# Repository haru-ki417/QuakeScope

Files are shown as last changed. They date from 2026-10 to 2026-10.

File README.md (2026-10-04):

# QuakeScope



**置いた場所の揺れを測り、気象庁の「計測震度」と同じ考え方で震度相当を出す、ESP32 の揺れ検知アラーム。**
強い揺れでは警報音を鳴らし、LINE・Telegram・Discord・メールに知らせます。判定エンジンは C++ で書き、本体とブラウザー（WebAssembly）で同じものを動かしています。

[**ブラウザーで試す**](https://haru-ki417.github.io/QuakeScope/) — 見本の地震や、スマホのセンサーで、本体と同じ判定を確かめられます。

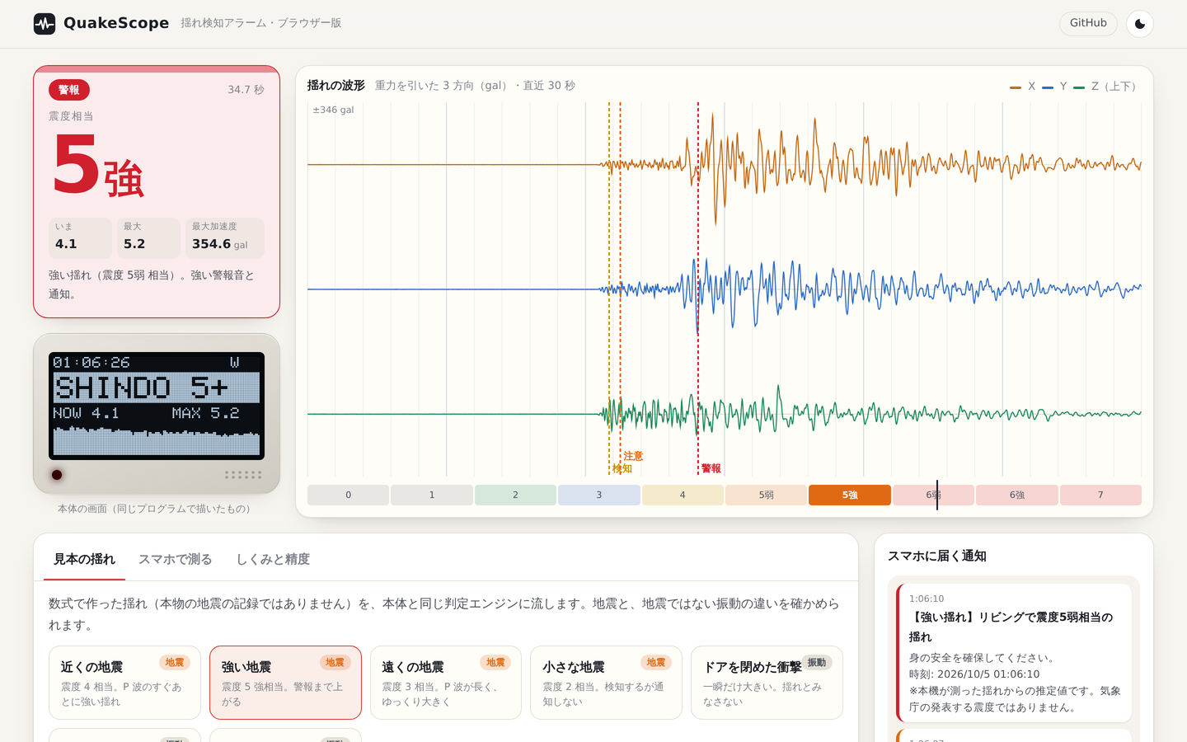
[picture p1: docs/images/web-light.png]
ブラウザー版: 震度 5 強相当の見本の地震を流したところ


> 本機の値は、置いた場所で測った揺れからの**推定（参考値）**です。気象庁の発表する震度・緊急地震速報ではありません。

## できること

| | |
|---|---|
| **震度相当** | 3 方向の加速度に、気象庁の計測震度と同じ周波数特性のフィルターをかけて計算（100 Hz・0.1 秒ごと）。揺れの最中から表示し、終わったら「この揺れの最大」を残す |
| **揺れ始め** | ふだんとの比（STA/LTA）で P 波をとらえ、短い音で知らせる。ドアや足音のような一瞬の衝撃は揺れとみなさない |
| **3 段階の警報** | 揺れ検知（震度 1 相当〜）・注意（震度 3 相当〜）・警報（震度 5 弱相当〜）。目安は変えられる |
| **通知** | LINE（Messaging API）・Telegram・Discord・メール（SMTP）。1 回の揺れで同じレベルは 1 度だけ、収まったらまとめ |
| **記録** | 揺れの要約 50 件と、揺れ始めの 5 秒前からの波形 8 件を本体に保存。スマホで見られる |
| **初期設定はスマホで** | 本体が自分の Wi-Fi を出し、スマホでつなぐと設定画面が開く。Wi-Fi・通知先・警報の目安を画面で設定 |
| **ケースと基板** | 3D プリントのケース（パラメーターで作り直せる）・回路図・ユニバーサル基板の配置と配線表・部品表 |

<p>
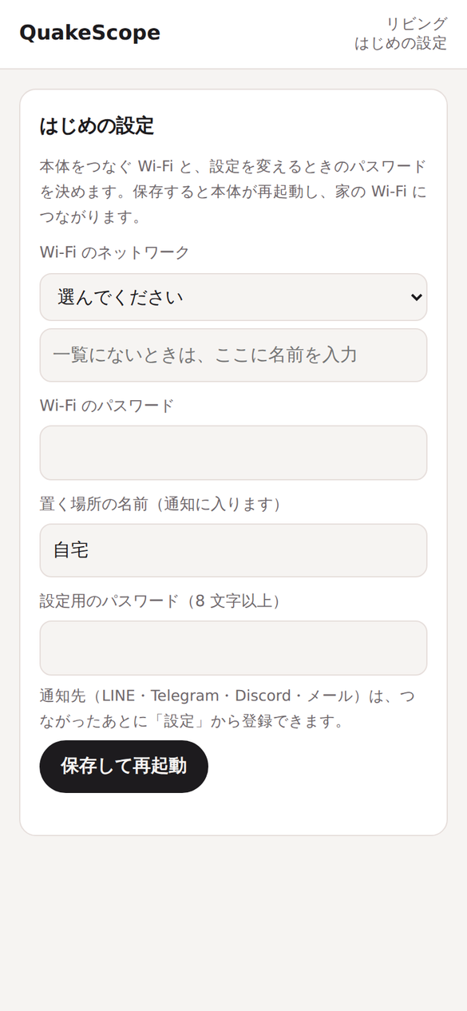
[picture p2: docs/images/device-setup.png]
はじめの設定

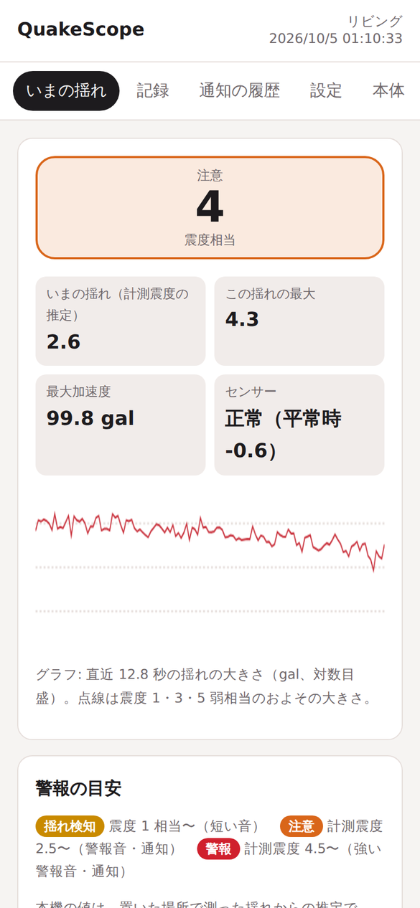
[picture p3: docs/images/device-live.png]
いまの揺れ

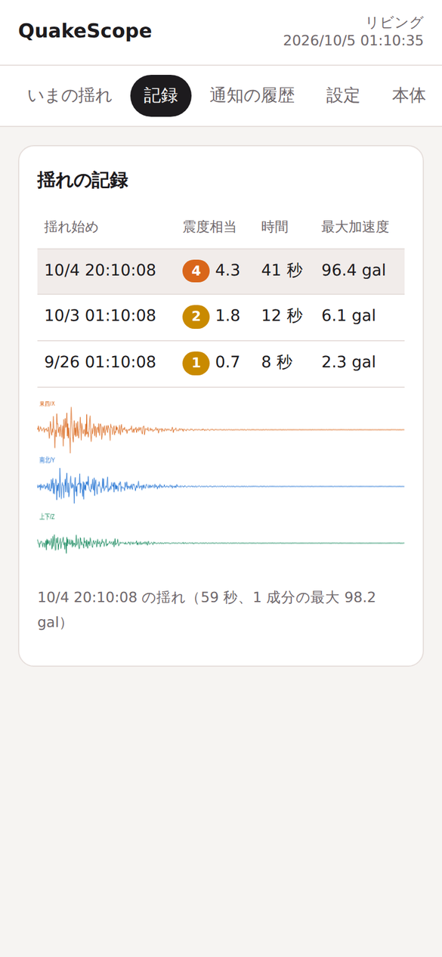
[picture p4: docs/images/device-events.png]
揺れの記録と波形

</p>

本体の設定画面（スマホ）。左から、はじめの設定・いまの揺れ・揺れの記録と波形。

## 精度

| 確かめたこと | 結果 |
|---|---|
| 本体の近似（IIR フィルター）と、気象庁の手順どおりの計算（周波数領域）の差 | 見本の地震 96 本で平均 0.024・最大 0.072 |
| 周波数領域の計算と、numpy で別に書いた計算の差 | 10⁻⁶ 以下 |
| 震度 3 以上の近い地震で、強い揺れ（S 波）の前にとらえるか | 5 通りすべて P 波から 1.5 秒以内 |
| ドア・足音・トラックで注意・警報にならないか | すべてならない |
| MPU6050 の雑音（約 3 gal）を入れた見本 | 雑音だけでは鳴らず、震度 3 以上はとらえる |

**限界**: 本体のセンサー（MPU6050）は雑音が大きいため、**震度 2 相当以下の小さな揺れは見逃すことがあります**。また、高い階やたなの上では、建物の揺れが加わって気象庁の震度より大きく出ることがあります。くわしくは[しくみと精度](docs/how-it-works.md)。

## 作る

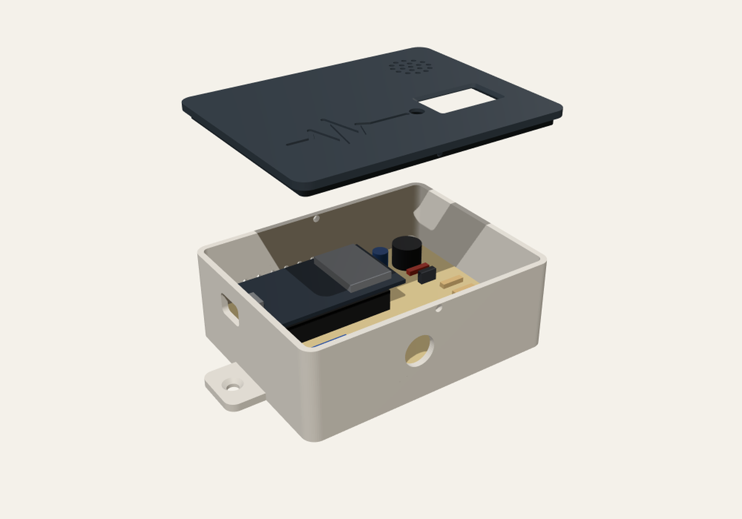
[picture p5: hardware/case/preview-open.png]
ケース


| | |
|---|---|
| [部品表](hardware/BOM.md) | ESP32-DevKitC-32E・GY-521（MPU6050）・0.96″ OLED・電磁ブザー・フルカラー LED・押しボタンなど。電子部品とケースで 4,500〜6,500 円が目安 |
| [回路図](hardware/schematic.svg) | 部品番号つき |
| [基板の配置と配線表](hardware/wiring.md) | 95×72 mm のユニバーサル基板。穴の番号で部品の位置と 29 本の配線を指定 |
| [ケース](hardware/case/) | `case_base.stl`・`case_lid.stl`。寸法は `case.mjs` の `PARAMS` で変えられる |
| [組み立てと書き込み](docs/assembly.md) | はんだ付けの順番・ファームウェアの書き込み・動作の確認・置き方 |

## 使う

- [使い方](docs/manual.md): はじめの設定・画面と LED の見方・ボタン・警報の目安・記録・更新・困ったとき
- [通知の設定](docs/notifications.md): LINE・Telegram・Discord・Gmail の手順

## 中身

```
core/          判定エンジン（C++17・端末に依存しない）とテスト
  src/         震度の計算・揺れの判定・通知の文面・画面の中身・見本の揺れ
  tests/       26 のテスト（275 項目）
  tools/       見本の揺れの CLI・numpy での確認
firmware/
  QuakeScope/  ESP32 のファームウェア（Arduino）。src/qs は core/src の写し
  web/         本体の設定画面（1 枚の HTML。gzip してファームウェアに入れる）
web/           ブラウザー版（WebAssembly・GitHub Pages）
hardware/      回路図・基板の配置・部品表・ケース
tools/         フィルターの係数を求める・core の写し・設定画面の埋め込み・本体のまね（モック）
docs/          使い方・通知・組み立て・しくみ
legacy/        試作 1 号機（Arduino Uno 版）のスケッチ
```

## 開発

```sh
# エンジンのテスト
cd core/tests && c++ -std=c++17 -O2 -Wall -Wextra -Werror -I../src test_core.cpp ../src/*.cpp -o test_core && ./test_core

# core/src を変えたら、ファームウェアに写す（CI は --check で確かめる）
python3 tools/sync_core.py

# 設定画面（firmware/web/index.html）を変えたら、ファームウェアに埋め込む
python3 tools/embed_web.py

# ブラウザー版の WebAssembly（wasi-sdk が要る）
WASI_SDK=/path/to/wasi-sdk web/build_wasm.sh
python3 -m http.server -d web 8000   # http://localhost:8000/

# 本体なしで設定画面を試す（見本の揺れを流す、本体のまね）
c++ -std=c++17 -O2 -Icore/src core/tools/qs_cli.cpp core/src/*.cpp -o qs_cli
python3 tools/mock_device.py ./qs_cli --port 8080          # 設定済みの本体
python3 tools/mock_device.py ./qs_cli --setup --port 8081  # はじめの設定

# ファームウェア
arduino-cli compile --fqbn esp32:esp32:esp32:PartitionScheme=min_spiffs firmware/QuakeScope

# 回路図・基板の配置・ケース
python3 tools/hw/schematic.py && python3 tools/hw/layout.py
cd hardware/case && npm install && node case.mjs
```

## 安全と法令について

- **気象業務法**: 気象庁以外の者が地震動の**予報**（ほかの場所の揺れや、これから来る揺れの予想）を業務として行うには、気象庁長官の許可が要ります。QuakeScope は、置いた場所で**測った揺れをそのまま表示・通知するだけ**で、予想はしません。通知の文にも、気象庁の震度ではないことを必ず入れています。参考: [気象庁「地震動の予報業務許可」](https://www.jma.go.jp/jma/kishou/minkan/minkan_jishin.html)
- **電波法（技適）**: 日本で使うときは、技適マークのある ESP32 モジュール（ESP32-WROOM-32E など）を使ってください。
- **電源**: PSE マークのある USB AC アダプターを使ってください。停電すると本体もルーターも止まります。[停電と通信](docs/manual.md#停電と通信)を見てください。
- **通知だけに頼らない**: 通信の混雑で、通知は遅れたり届かなかったりします。強い揺れを感じたら、まず身の安全を確保してください。

## 試作 1 号機

QuakeScope は、Arduino Uno で作った「地震即時アラートシステム」を作り直したものです。試作のスケッチと、作り直すときに見つけた問題と対処を [legacy/uno-prototype](legacy/uno-prototype/) に残しています。

## ライセンス

[MIT License](LICENSE)。ほかの人が作ったものは [THIRD_PARTY.md](THIRD_PARTY.md)。

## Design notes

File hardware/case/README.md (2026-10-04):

# ケース

| ファイル | 中身 |
|---|---|
| `case_base.stl` | 底（基板を留める柱 4 本・USB の口・前の壁にボタンの穴・後ろの壁に空気の通り道・左右に床へ留める耳） |
| `case_lid.stl` | ふた（OLED の窓・LED の穴・ブザーの音の穴・地震計の波形の模様）。印刷する向き（表を下）で入っている |
| `case.mjs` | 上の 2 つを作るプログラム。寸法は先頭の `PARAMS` で変えられる |

外形は 102.8 × 79.8 × 38.6 mm（耳を除く）。印刷の設定と組み立ては[組み立てと書き込み](../../docs/assembly.md)を見てください。

```sh
npm install     # manifold-3d
node case.mjs   # STL を作り直す（../layout.json の部品の位置に合わせて穴を開ける）
```

| 組み立てた姿 | 中 | ふたの裏 |
|---|---|---|
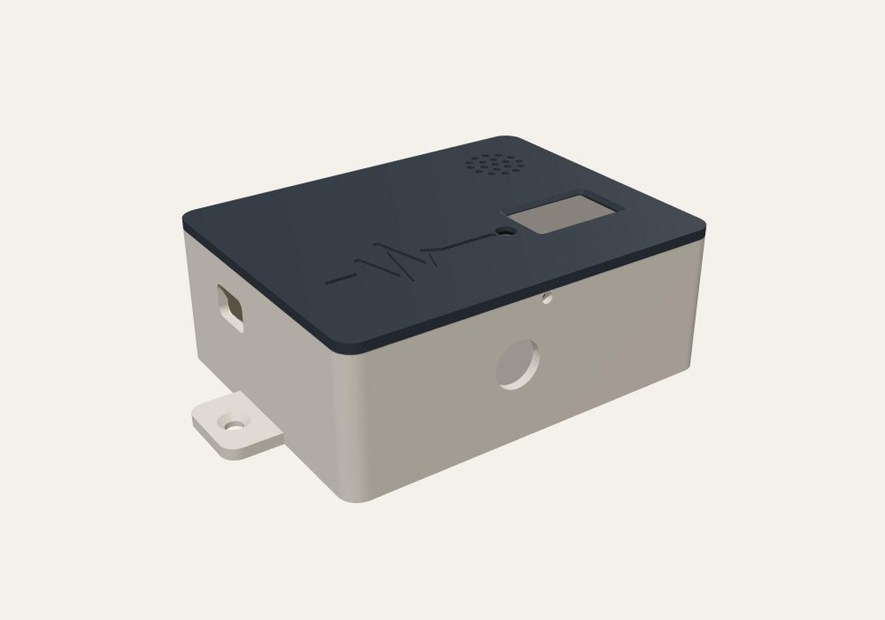
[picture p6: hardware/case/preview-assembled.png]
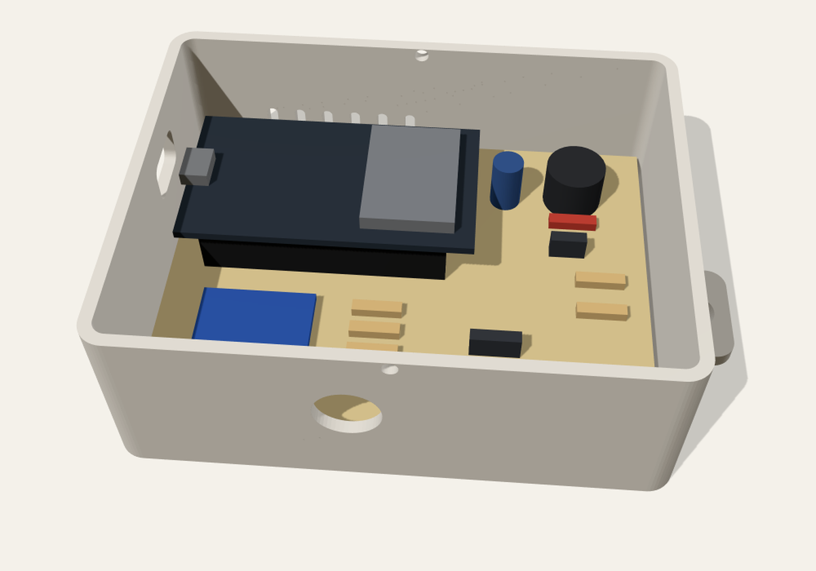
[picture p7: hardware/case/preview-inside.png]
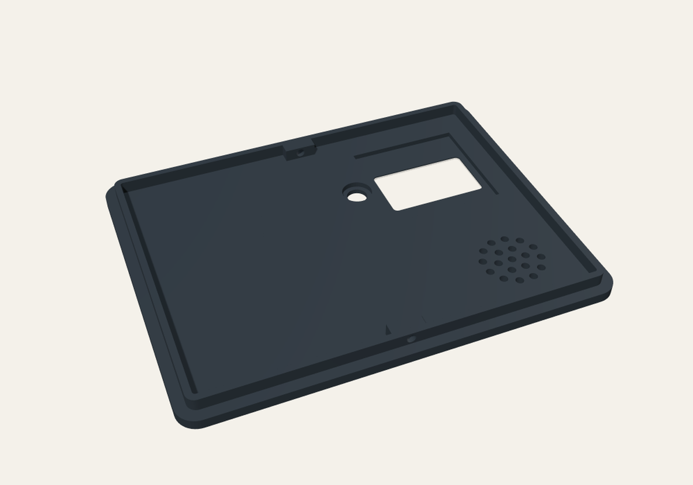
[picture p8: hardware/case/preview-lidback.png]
|  |  |  |

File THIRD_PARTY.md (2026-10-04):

# ほかの人が作ったもの

QuakeScope は、次のソフトウェアを使っています。

| 名前 | 使っている所 | ライセンス | リポジトリに含むか |
|---|---|---|---|
| [Adafruit SSD1306](https://github.com/adafruit/Adafruit_SSD1306) | ファームウェア（OLED） | BSD | 含まない（Arduino のライブラリマネージャーで入れる） |
| [Adafruit GFX Library](https://github.com/adafruit/Adafruit-GFX-Library) | ファームウェア（文字・図形） | BSD | 文字の形（glcdfont.c の ASCII 部分）だけ `web/js/font5x7.js` に含む |
| [Adafruit BusIO](https://github.com/adafruit/Adafruit_BusIO) | ファームウェア | MIT | 含まない |
| [Arduino core for ESP32](https://github.com/espressif/arduino-esp32) | ファームウェア | LGPL-2.1 | 含まない |
| [manifold-3d](https://github.com/elalish/manifold) | ケースの STL を作る道具 | Apache-2.0 | 含まない（`npm install` で入れる） |
| [wasi-sdk](https://github.com/WebAssembly/wasi-sdk) | ブラウザー版の WebAssembly を作る道具 | Apache-2.0 WITH LLVM-exception | 道具は含まない。`web/qs.wasm` には、その C/C++ ランタイム（wasi-libc・libc++）の一部が入る |

## Adafruit GFX Library（glcdfont.c）

```
Software License Agreement (BSD License)

Copyright (c) 2012 Adafruit Industries.  All rights reserved.

Redistribution and use in source and binary forms, with or without
modification, are permitted provided that the following conditions are met:

- Redistributions of source code must retain the above copyright notice,
  this list of conditions and the following disclaimer.
- Redistributions in binary form must reproduce the above copyright notice,
  this list of conditions and the following disclaimer in the documentation
  and/or other materials provided with the distribution.

THIS SOFTWARE IS PROVIDED BY THE COPYRIGHT HOLDERS AND CONTRIBUTORS "AS IS"
AND ANY EXPRESS OR IMPLIED WARRANTIES, INCLUDING, BUT NOT LIMITED TO, THE
IMPLIED WARRANTIES OF MERCHANTABILITY AND FITNESS FOR A PARTICULAR PURPOSE
ARE DISCLAIMED. IN NO EVENT SHALL THE COPYRIGHT HOLDER OR CONTRIBUTORS BE
LIABLE FOR ANY DIRECT, INDIRECT, INCIDENTAL, SPECIAL, EXEMPLARY, OR
CONSEQUENTIAL DAMAGES (INCLUDING, BUT NOT LIMITED TO, PROCUREMENT OF
SUBSTITUTE GOODS OR SERVICES; LOSS OF USE, DATA, OR PROFITS; OR BUSINESS
INTERRUPTION) HOWEVER CAUSED AND ON ANY THEORY OF LIABILITY, WHETHER IN
CONTRACT, STRICT LIABILITY, OR TORT (INCLUDING NEGLIGENCE OR OTHERWISE)
ARISING IN ANY WAY OUT OF THE USE OF THIS SOFTWARE, EVEN IF ADVISED OF THE
POSSIBILITY OF SUCH DAMAGE.
```

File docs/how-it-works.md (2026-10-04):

# しくみと精度

QuakeScope の中心は、端末に依存しない C++17 の判定エンジン（`core/src`）です。同じソースを、ESP32 のファームウェアと、ブラウザー版（WebAssembly）の両方で使っています。

```
加速度センサー（100 Hz）
   │  3 方向の加速度（重力を含む）
   ▼
校正 ── 最初の 3 秒で重力の向きを測り、引く（どの向きに置いても動く）
   │
   ├─▶ 震度のフィルター（IIR 2 次 × 5 段）──▶ いまの震度（5 秒の窓）・この揺れの最大
   │
   ├─▶ 1〜10 Hz の帯域 ──▶ STA/LTA（揺れ始め）・一瞬の衝撃の除去
   │
   └─▶ 平常時の震度（雑音の床）
            │
            ▼
      揺れの始まり・レベル（検知／注意／警報）・終わり ──▶ 画面・LED・音・通知・記録
```

## 震度相当の計算

気象庁の[計測震度の算出方法](https://www.jma.go.jp/jma/kishou/know/jishin/kyoshin/kaisetsu/calc_sindo.html)は、次のとおりです。

1. 3 方向の加速度をフーリエ変換し、周期の効果・高い周波数を落とす・低い周波数を落とす、の 3 つのフィルターをかけて戻す。
2. 3 方向を合わせた大きさ（ベクトルの長さ）が、合計 0.3 秒以上になる値 *a* を求める。
3. *I* = 2 log₁₀ *a* + 0.94。小数第 3 位を四捨五入し、小数第 2 位を切り捨てる。

この計算は記録が終わってからでないとできないため、本体では次のように近似しています。

- **フィルター**: 気象庁のフィルターの周波数特性を、100 Hz で動く 2 次の IIR フィルター 5 段（`core/src/jma_filter_coeffs.h`）に合わせました。合わせ方は `tools/fit_jma_digital.py` にあります。0.3〜12 Hz で、気象庁の式との差は最大 0.55 dB です。
- **0.3 秒の値**: 100 Hz では 0.3 秒は 30 サンプルなので、「揺れている間のフィルター後の大きさのうち、大きい方から 30 番目」を求めればよい。これを 30 個だけ持つ最小ヒープで、揺れの間ずっと更新します（メモリーは一定）。
- **いまの震度**は、直近 5 秒の窓で同じ計算をしたものです。

確かめ方:

- `core/src/intensity.cpp` の `computeJmaIntensity` は、気象庁の手順どおりに周波数領域で計算します。これを numpy で別に書いた計算（`core/tools/check_exact.py`）と比べ、差は 10⁻⁶ 以下でした。
- 見本の地震（近い・遠い、計測震度 1〜6、種を変えて 96 本）で、本体の近似と周波数領域の計算の差は**平均 0.024・最大 0.072** です（`core/tests`）。震度の階級は 1.0 刻みなので、階級が変わるのは境目のごく近くだけです。

## 揺れ始めと、誤報の防ぎ方

| しくみ | 中身 | ねらい |
|---|---|---|
| STA/LTA | 1〜10 Hz の帯域で、直近 0.5 秒と 10 秒の平均の強さの比が 3 を超えたら候補 | 小さな P 波でも、ふだんとの違いでとらえる |
| 揺れが続いたか | 直近 1 秒のうち 0.3 秒以上、「直近の最大の 1/4」と「雑音の 2 倍」の両方を超えていたか | ドア・足音のような一瞬の衝撃を除く |
| 雑音の床 | 揺れていないときの震度を追いかける（下がるのは速く・上がるのは 60 秒かけて） | 雑音の多いセンサーでも、雑音で鳴らない |
| 揺れの始まり | 上の 2 つに加えて、震度が「雑音の床 + 0.6」以上 | |
| 終わり | 震度が「雑音の床 + 0.3」を下回り、STA/LTA も落ち着いた状態が 8 秒続いたら | |

見本の揺れでの結果（`core/tests`・ブラウザー版の「しくみと精度」で同じものを確かめられます）:

- 震度 3 以上の近い地震で、強い揺れ（S 波）が来る**前の P 波の段階**で揺れ始めをとらえる（P 波から 1.5 秒以内）。
- ドアを閉めた衝撃・足音（各 6 通り）では、揺れとみなさない。トラックの振動では「検知」まではしても、注意・警報にはならない。
- 警戒レベル: 計測震度 1.5〜2.2 は「検知」まで、2.8〜4.0 は「注意」、4.8〜6.2 は「警報」になる。

## センサーの雑音について

MPU6050 の雑音は、データシートで 400 µg/√Hz です。100 Hz で読むと 1 方向あたり約 3 gal になり、そのまま震度の計算に入れると、**置いておくだけで計測震度 1.5 ほど**になります。最初の版はこれを考えておらず、雑音だけで「揺れの始まり」と判定したり、「揺れが終わらない」状態になったりすることが、雑音を入れた見本で分かりました。

そこで「雑音の床」を測り、それより十分大きい揺れだけを扱うようにしました。雑音 3 gal の見本で:

| 見本 | 結果 |
|---|---|
| 揺れなし 5 分（3 通り） | 揺れとみなさない |
| ドア・足音・トラック（各 3 通り） | 注意・警報にならない |
| 近い地震 震度 3 相当・4.5 相当（各 3 通り） | とらえて注意以上になり、終わりも分かる。震度の差は 0.25 以内 |

その代わり、**震度 2 相当以下の小さな揺れは見逃すことがあります**。もっと小さな揺れまで測りたいときは、雑音の小さいセンサー（例: ADXL355、25 µg/√Hz）に替えるのが根本的な対策です（現在の版は MPU6050 のみ対応）。

## 気象庁の震度との違い

- 気象庁の震度計は、地面や低い建物の 1 階に、しっかり固定して置かれています。本機を高い階やたなの上に置くと、建物やたなの揺れが加わって、**大きく出ることがあります**。
- 本機の値は、本機を置いた 1 点の揺れです。同じ建物の中でも、場所によって変わります。
- 本機は、自分が測った揺れを表示・通知するだけです。ほかの場所の揺れや、これから来る揺れを予想しません。

## 本体のソフトウェアの構成

| 部分 | 動く場所 | 中身 |
|---|---|---|
| センサーの読み取り | コア 1・優先度 10・20 ms ごと | MPU6050 の FIFO から 100 Hz のサンプルを読み、エンジンと波形の記録に渡す |
| 判定エンジン | 同じ | 上のとおり。出来事（揺れ始め・レベル・終わり・センサー異常）をキューに入れる |
| 画面・LED・音・ボタン | メインのループ | 0.1 秒ごとに画面を更新 |
| 通知 | コア 0・別のタスク | HTTPS（LINE・Telegram・Discord）と SMTP。失敗したら 3 回まで送り直す |
| 記録 | メインのループ | LittleFS に要約（JSON）と波形（50 Hz、int16）。容量が減ったら古いものから消す |
| 設定の画面 | メインのループ | WebServer。設定は NVS に保存。秘密の値は画面に返さない |

## テスト

```sh
cd core/tests
c++ -std=c++17 -O2 -Wall -Wextra -Werror -I../src test_core.cpp ../src/*.cpp -o test_core && ./test_core
```

26 のテスト（275 項目）: 震度の階級の境目・丸め方・フィルターの式・正弦波での理論値・重力の影響・リアルタイムと周波数領域の一致・見本の揺れの再現性・校正・誤報・レベル・P 波での検知・揺れの要約・壁付け・センサーの故障・雑音の多いセンサー・画面・波形の記録・通知の回数の制限・文面・JSON・Base64 など。

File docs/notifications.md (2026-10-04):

# 通知の設定

QuakeScope は、注意・警報の揺れと、揺れがおさまったときのまとめを、次の 4 つに送れます。いくつでも同時に使えます。

| 送り先 | 用意するもの | 費用 | 向いている人 |
|---|---|---|---|
| [LINE](#line) | LINE 公式アカウント（Messaging API） | 月 200 通まで無料 | 家族みんなが LINE を使っている |
| [Telegram](#telegram) | Bot のトークンとチャット ID | 無料 | 設定がいちばん簡単 |
| [Discord](#discord) | Webhook の URL | 無料 | 家族やチームのサーバーがある |
| [メール](#メールgmail) | Gmail のアプリ パスワード | 無料 | どの端末でも受け取りたい |

届く文の例:

```
【揺れを検知】リビングで震度3相当の揺れを検知しました。
時刻: 2026/10/5 14:23:07
※本機が測った揺れからの推定値です。気象庁の発表する震度ではありません。
```

```
【揺れがおさまりました】リビング 最大震度3相当
揺れ始め: 2026/10/5 14:23:07
揺れていた時間: 約41秒
最大加速度: 52 gal
計測震度（推定）: 3.4
※本機が測った揺れからの推定値です。気象庁の発表する震度ではありません。
```

設定した値は、本体の中（ESP32 の不揮発メモリー）だけに保存します。設定の画面には、保存した値を表示しません（「設定済み」とだけ出ます）。

---

## LINE

以前の「LINE Notify」は 2025 年 3 月 31 日で終わったため、**LINE 公式アカウントの Messaging API** を使います。自分専用の公式アカウントを作り、そこから自分（や家族）に送る形です。

1. [LINE 公式アカウント](https://entry.line.biz/start/jp/)を作ります（無料のコミュニケーションプラン）。
2. [LINE Official Account Manager](https://manager.line.biz/) で、作ったアカウントの「設定」→「Messaging API」→「Messaging API を利用する」を押します。プロバイダーは新しく作ってかまいません。
   - 2024 年 9 月 4 日から、LINE Developers コンソールで Messaging API のチャネルを直接作ることはできなくなっています。この手順で作ります。
3. [LINE Developers コンソール](https://developers.line.biz/console/)を開き、同じプロバイダーの中のチャネルを選びます。
4. 「Messaging API 設定」タブの下の方で、**チャネルアクセストークン（長期）**を「発行」してコピーします。
5. 「チャネル基本設定」タブの**あなたのユーザー ID**（`U` から始まる 33 文字）をコピーします。
6. 「Messaging API 設定」タブの QR コードを、通知を受けたい LINE で読み、**友だちに追加**します。
7. QuakeScope の設定の画面の「通知」→「LINE」に、4 のトークンと 5 のユーザー ID を入れて保存し、「テスト通知を送る」を押します。

**無料で送れるのは月 200 通まで**です（コミュニケーションプラン。上限を超えると送れなくなり、エラーになります）。通常の使い方（1 回の揺れで 2〜3 通）なら足ります。家族にも送りたいときは、Telegram の グループや Discord を使うと通数を気にせずに済みます。

参考: [Messaging API を始めよう](https://developers.line.biz/ja/docs/messaging-api/getting-started/)・[Messaging API の料金](https://developers.line.biz/ja/docs/messaging-api/pricing/)

## Telegram

1. Telegram で [@BotFather](https://t.me/BotFather) を開き、`/newbot` を送ります。名前を 2 回聞かれるので答えると、**Bot のトークン**（`123456789:AA...`）が届きます。
2. 作った Bot を開き、何か 1 通送ります（「こんにちは」など）。
3. ブラウザーで `https://api.telegram.org/bot<トークン>/getUpdates` を開き、`"chat":{"id":` のあとの数字をコピーします。これが**チャット ID** です。
   - 家族のグループに送りたいときは、Bot をグループに入れて、グループで 1 通送ってから同じページを開きます（グループの ID は `-` から始まります）。
4. QuakeScope の設定の画面の「通知」→「Telegram」に、トークンとチャット ID を入れて保存し、「テスト通知を送る」を押します。

## Discord

1. 通知を受けたいサーバーの、チャンネルの歯車（チャンネルの編集）→「連携サービス」→「ウェブフック」→「新しいウェブフック」を押します。
2. 名前を「QuakeScope」などにして、「ウェブフック URL をコピー」を押します。
3. QuakeScope の設定の画面の「通知」→「Discord」に URL を入れて保存し、「テスト通知を送る」を押します。

## メール（Gmail）

Gmail は、ふだんのパスワードでは送れません。**2 段階認証を有効にしたうえで、アプリ パスワード**を作ります。

1. Google アカウントの「セキュリティ」で、**2 段階認証プロセス**を有効にします。
2. Google アカウントの検索欄で「アプリ パスワード」を探して開き、名前（QuakeScope）を入れて作ります。16 文字のパスワードが出ます。
3. QuakeScope の設定の画面の「通知」→「メール」に、次のように入れます。

| 項目 | 値 |
|---|---|
| SMTP サーバー | `smtp.gmail.com` |
| ポート | `465（SSL）`（つながらなければ `587（STARTTLS）`） |
| ユーザー名 | 自分の Gmail アドレス |
| パスワード | 2 の 16 文字（空白は入れない） |
| 宛先 | 受け取るアドレス（カンマで区切って複数） |

4. 保存して「テスト通知を送る」を押します。迷惑メールに入ることがあるので、最初は迷惑メールのフォルダーも見てください。

ほかのメールサービスでも、SMTP（465 か 587、ユーザー名とパスワードで認証）に対応していれば使えます。

## うまくいかないとき

設定の画面の「通知の履歴」に、送った結果が出ます。

| 出る内容 | 原因と対処 |
|---|---|
| `401` | トークンやパスワードが違う。コピーし直す（前後の空白に注意） |
| `400`（LINE） | ユーザー ID が違うか、Bot を友だちに追加していない |
| `400`（Telegram） | チャット ID が違うか、Bot に 1 通も送っていない |
| `404`（Discord） | ウェブフックが消されている。作り直す |
| `429` | 送りすぎ。しばらくすると送れる（本体は自動で送り直す） |
| 接続できない | 本体がインターネットにつながっているか。時刻が合っているか（画面の時計） |
| `535`（メール） | 認証の失敗。アプリ パスワードを使っているか。2 段階認証が有効か |

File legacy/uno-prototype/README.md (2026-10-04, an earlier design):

# 試作 1 号機（Arduino Uno 版）

QuakeScope の出発点になった、最初の「地震即時アラートシステム」のスケッチです。記録のため、**当時のまま**残しています（`Seismometer_main_unit.ino`）。このスケッチは今の QuakeScope では使いません。

## 構成

| 部品 | 役目 |
|---|---|
| Arduino Uno | 揺れの計算・表示・警報 |
| アナログ出力の 3 軸加速度センサー（A0〜A2） | 揺れを測る |
| DS3231（RTC） | 時刻 |
| SSD1306 OLED 128×32 | 揺れのグラフ・時刻 |
| ESP-01S（SoftwareSerial、別のスケッチ） | 通知 |
| LED・ブザー | 警報 |

## 作り直すときに見つけた問題と、QuakeScope での対処

| 試作 1 号機 | 何が起きるか | QuakeScope |
|---|---|---|
| `if (shakeMagnitude <= SHAKE_THRESHOLD_S)` のように、**比べる向きが逆** | 揺れていないとき（値が小さいとき）に警報になり、揺れると止まる | 揺れの大きさが基準を**超えた**ときに判定。テストで確かめている |
| `maxShake` を `<` で更新し、初期値が 1.0 | 「最大」に最小値が入る | この揺れの最大を、0.3 秒の基準どおりに求める |
| P 波・S 波を、揺れの**大きさ**のしきい値で分けている | P 波・S 波は届く順番の違いなので、大きさでは区別できない | P 波はふだんとの比（STA/LTA）でとらえ、強さは震度相当で段階を分ける |
| 合成加速度と 1 G の差を「揺れ」とする | 傾きやセンサーの誤差で、揺れていなくても値が出る。横揺れが小さく出る | 起動時に重力の向きを 3 方向で測って引く（どの向きに置いても動く） |
| `delay(50)` と画面の描画で、読む間隔が 50 ms 以上・不ぞろい | 周波数を使う震度の計算ができない | センサーの FIFO で 100 Hz ちょうどに読む（別のタスク） |
| ESP-01S に文字を送るだけ | 通知が届いたか分からない | ESP32 1 枚で、HTTPS の応答を見て送り直す。結果を履歴に残す |
| しきい値が加速度（G）の固定値 | 体感の震度と結びつかない | 気象庁の計測震度と同じ考え方で計算した「震度相当」 |

試作で「揺れを感じたら知らせる」流れを形にできたことが、そのまま QuakeScope の設計の土台になっています。

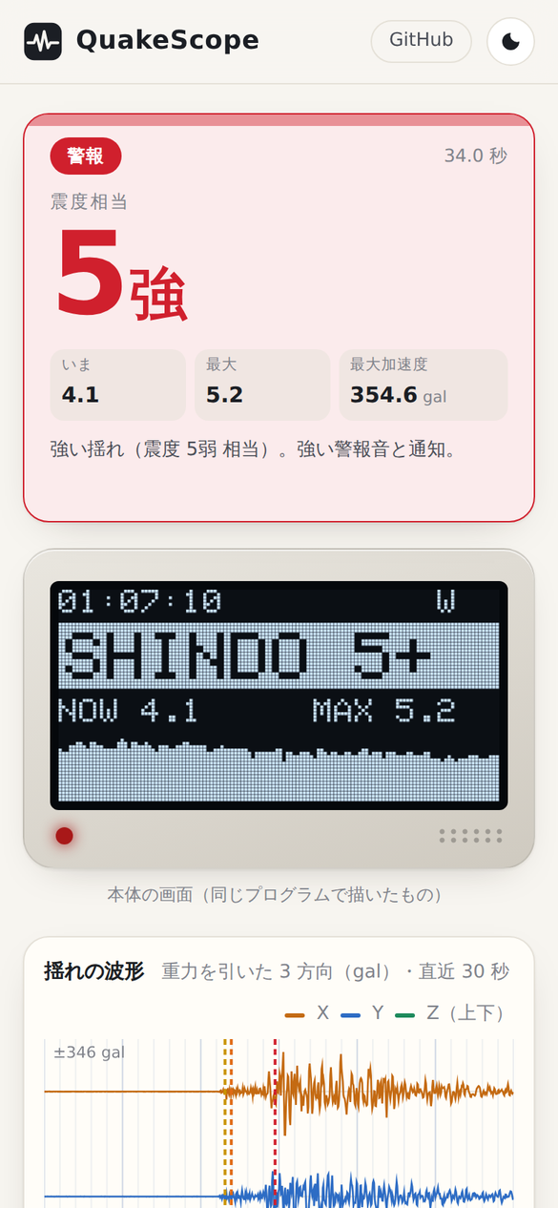
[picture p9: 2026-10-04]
docs/images/web-phone.png

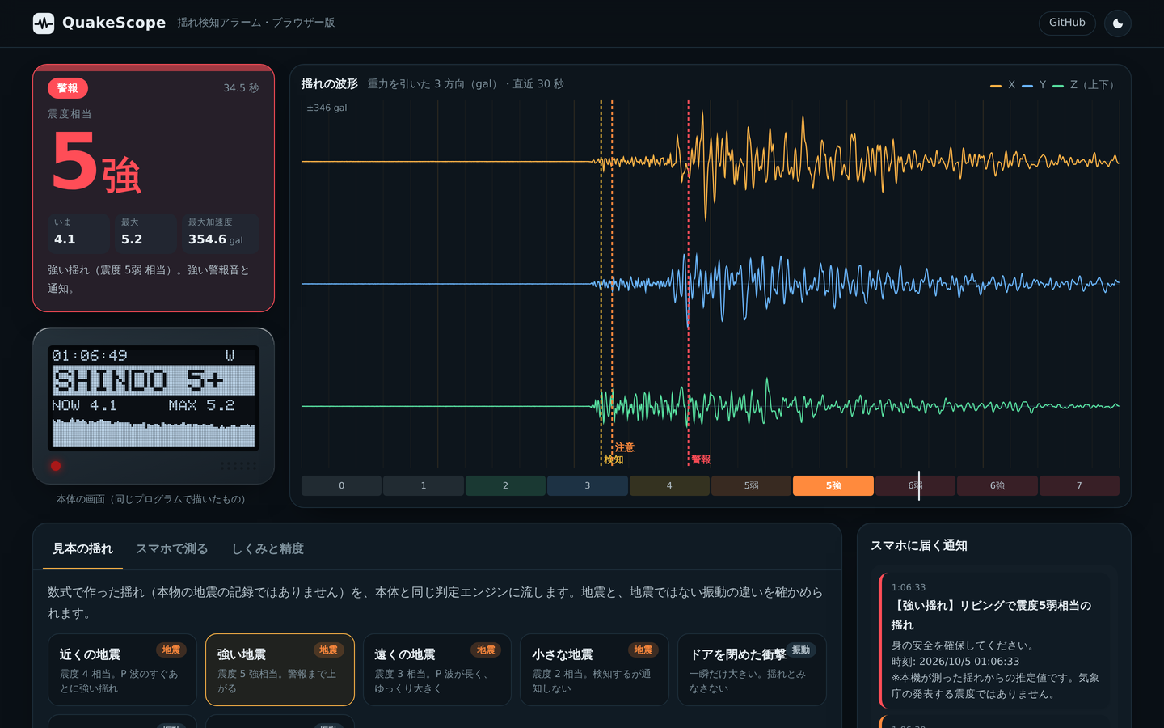
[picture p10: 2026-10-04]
docs/images/web-dark.png

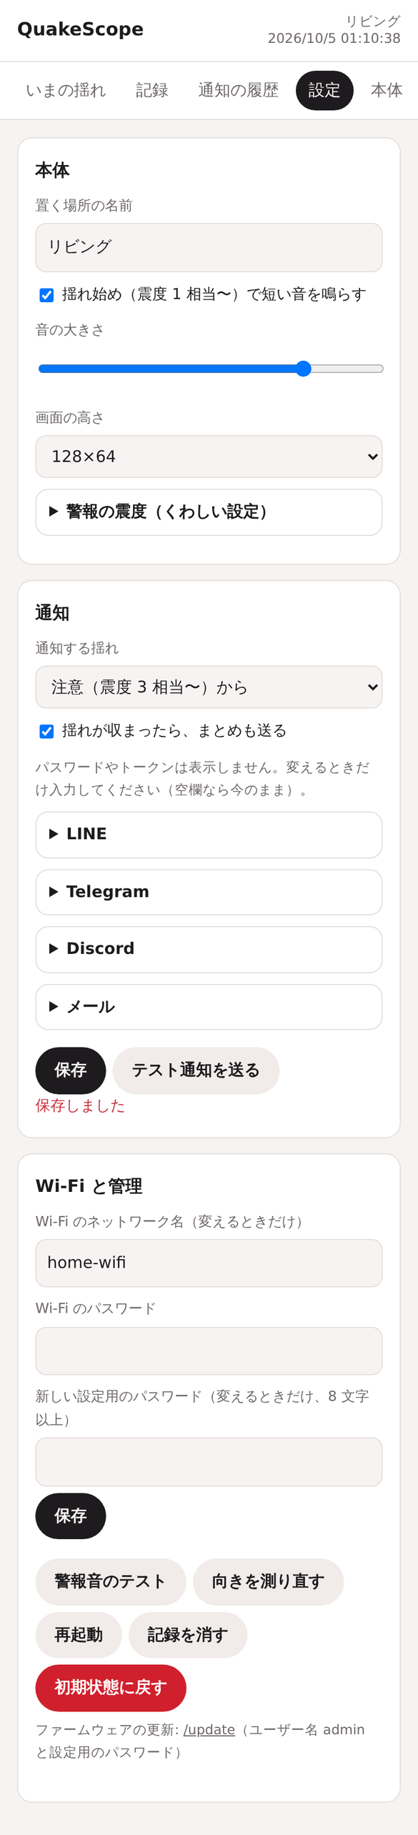
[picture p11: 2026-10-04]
docs/images/device-settings.png

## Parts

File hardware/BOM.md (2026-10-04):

# 部品表（BOM）

部品番号は[回路図](schematic.svg)・[基板の配置](wiring.md)と同じです。

価格は 2026 年 10 月時点の**目安**です。販売店の画面を直接確かめられなかった部品もあるので、買う前にお店で確認してください。

## 電子部品

| 番号 | 部品 | 数 | 例（買える所） | 目安 |
|---|---|---|---|---|
| U1 | ESP32-DevKitC-32E（ESP32-WROOM-32E・4MB・技適あり） | 1 | 秋月電子 [115673](https://akizukidenshi.com/catalog/g/g115673/) | 1,800〜2,200 円 |
| U2 | GY-521（MPU6050 加速度・ジャイロ） | 1 | 通販各社（複数個入りが多い） | 300〜700 円 |
| U3 | 0.96″ OLED 128×64（SSD1306・I²C） | 1 | 秋月電子 [115870](https://akizukidenshi.com/catalog/g/g115870/)（青）・[112031](https://akizukidenshi.com/catalog/g/g112031/)（白） | 500〜700 円 |
| BZ1 | 電磁ブザー 12 mm（**発振回路なし**・5V・足の間隔 7.6 mm） | 1 | 秋月電子など | 50〜150 円 |
| Q1 | NPN トランジスター 2SC1815（GR） | 1 | 秋月電子など | 10〜20 円 |
| D1 | ダイオード 1N4148 | 1 | 秋月電子など | 5〜10 円 |
| R1 | 抵抗 1kΩ（1/6W〜1/4W） | 1 | | 1〜5 円 |
| R2 | 抵抗 10kΩ | 1 | | 1〜5 円 |
| R3 | 抵抗 330Ω | 1 | | 1〜5 円 |
| R4, R5 | 抵抗 100Ω | 2 | | 1〜5 円 |
| C1 | 電解コンデンサー 100µF 16V | 1 | | 10〜20 円 |
| LED1 | 5 mm フルカラー LED（**カソード共通**・拡散） | 1 | 秋月電子など | 30〜60 円 |
| SW1 | 押しボタン 12 mm（モーメンタリ・穴 12 mm） | 1 | 通販各社 | 100〜300 円 |
| — | ピンソケット 1×19（1×20 を切ってもよい） | 2 | | 80〜160 円 |
| — | L 型ピンヘッダー（1×4 を 2、1×2 を 1） | 1 式 | | 20〜50 円 |
| — | ユニバーサル基板 95×72 mm・2.54 mm ピッチ | 1 | サンハヤト ICB-293GV など | 200〜400 円 |
| — | ジャンパーワイヤー（メス-メス）10 cm | 10 本 | | 200〜400 円 |
| — | 被覆線（UEW 0.26 mm や単線） | 少し | | 200 円 |

## ケースと取り付け

| 部品 | 数 | 目安 |
|---|---|---|
| 3D プリントのケース（[底](case/case_base.stl)・[ふた](case/case_lid.stl)、PLA か PETG で約 80 g） | 1 式 | 200〜300 円（材料代） |
| M3 タッピングねじ 6 mm（基板を留める） | 4 | |
| M2.6 タッピングねじ 6 mm（ふたを留める） | 2 | |
| 木ねじ 4 mm（耳を床やたなに留める）か、強力な両面テープ | 2 | |
| 薄い両面テープ（クッションのないもの。センサーの下に） | 少し | |

## 電源

| 部品 | 数 | 目安 |
|---|---|---|
| USB AC アダプター 5V・1A 以上（**PSE マークのあるもの**） | 1 | 500〜1,000 円 |
| USB ケーブル（micro-B・データ用でなくてよい） | 1 | 200〜500 円 |
| 停電に備えるなら: 給電しながら充電できるモバイルバッテリー | 1 | 2,000 円〜 |

**合計の目安**: 電子部品とケースで 4,500〜6,500 円（電源・工具は別）。

## 工具

はんだごて（温度調節つきが楽）・はんだ・ニッパー・テスター（導通チェック）・3D プリンター（なければ出力サービス）・プラスドライバー。

## 部品を選ぶときの注意

- **ブザーは「発振回路なし（電磁型・自励なし）」**を選ぶ。発振回路つきは 1 つの音しか出ず、警報の音の区別ができない。
- **フルカラー LED は「カソード共通」**。アノード共通だと、色が逆になって光らない。
- **OLED は I²C（4 本足）**。SPI（6〜7 本足）ではない。足の並び（GND と VCC の順）は製品で違うので、基板の印刷を見てつなぐ。
- **2SC1815 は、平らな面を手前にして左から E・C・B**。2N3904 などで代用するときは足の並びが違う（E・B・C）ので注意。
- **ESP32 は技適マークのあるもの**（ESP32-WROOM-32E の金属カバーに印刷）を使う。日本で電波を出すために必要。

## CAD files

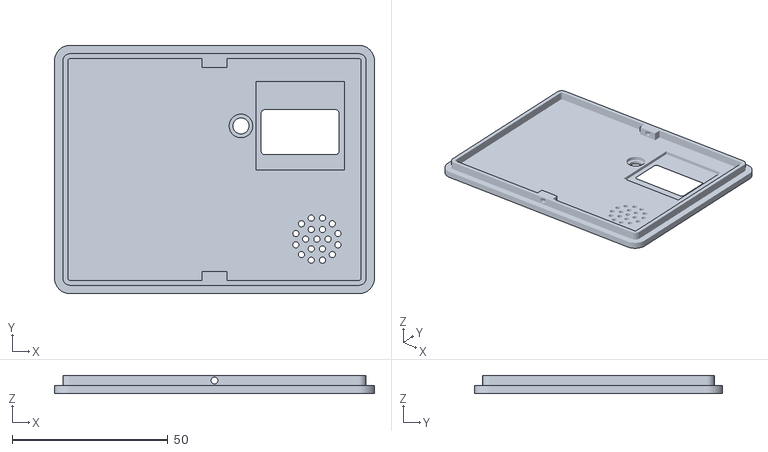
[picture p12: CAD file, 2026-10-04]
hardware/case/case_lid.stl
102.8 x 79.8 x 5.80

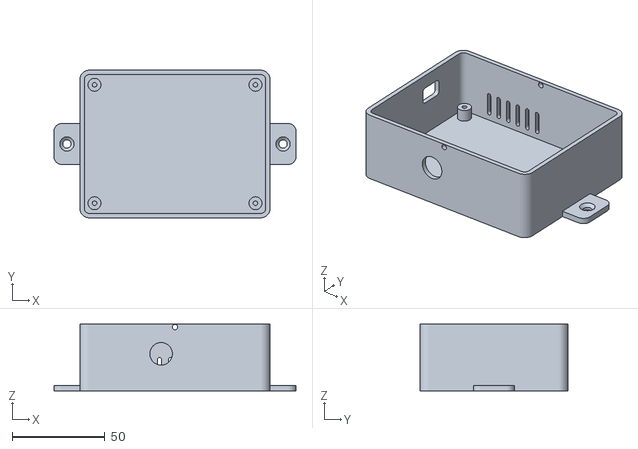
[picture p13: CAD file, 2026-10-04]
hardware/case/case_base.stl
130.8 x 79.8 x 36.0

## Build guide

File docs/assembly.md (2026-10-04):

# 組み立てと書き込み

はんだ付けが初めてでも、3〜4 時間で組み立てられる量です。部品は[部品表](../hardware/BOM.md)、つなぎ方は[回路図](../hardware/schematic.svg)と[基板の配置と配線表](../hardware/wiring.md)を見てください。

組み立てたケースの中

## 1. ケースを 3D プリントする

| ファイル | 向き | 設定の目安 |
|---|---|---|
| [case_base.stl](../hardware/case/case_base.stl) | 底を下 | PLA か PETG・0.2 mm・壁 3 周・充填 20%・サポートなし |
| [case_lid.stl](../hardware/case/case_lid.stl) | 表（平らな面）を下 | 同じ |

- 印刷に 4〜5 時間かかります。
- ふたがきついときは、`hardware/case/case.mjs` の `fit` を 0.4 に、ゆるいときは 0.2 にして作り直します（下の「ケースの寸法を変える」）。
- OLED は製品によって寸法が少しずつ違います。手元の OLED の基板の大きさを測って、`oled` の `w`・`h` を合わせてください。

### ケースの寸法を変える

```sh
cd hardware/case
npm install          # manifold-3d（ケースを作る計算のライブラリ）を入れる
node case.mjs        # case_base.stl と case_lid.stl を作り直す
```

基板の部品の位置を変えたときは、先に `python3 tools/hw/layout.py` で `hardware/layout.json` を作り直します。ブザーの音の穴などは、この配置に合わせて開きます。

## 2. 基板を作る

基板の配置と配線

1. **低い部品から**付けます。抵抗（R1〜R5）→ ダイオード（D1、帯を 5V 側）→ トランジスター（Q1、平らな面を手前）→ 電解コンデンサー（C1、足の長い方が +）→ ブザー（BZ1、+ の印を 5V 側）。
2. **ピンソケット 2 本**を付けます。ESP32 を挿したまま付けると、間隔がずれません（ESP32 の足は熱で傷まない程度に、手早く）。
3. **L 型ピンヘッダー**（J3・J4・J5）を、足が基板の外側を向くように付けます。
4. **加速度センサー（U2）**: ピンヘッダーの黒い台を抜いて、センサーの基板を低く付けます。センサーと基板のすき間に、クッションのない薄い両面テープを挟んで密着させます。**ここが浮いていたりぐらついたりすると、本当の揺れより大きく測ります。**
5. [配線表](../hardware/wiring.md)の順に、はんだ面で配線します。1 本ごとにテスターで導通を確かめ、表に印をつけていくと抜けがありません。
6. 最後に、**5V と GND、3.3V と GND がつながっていない**ことをテスターで確かめます（つながっていたら、どこかでショートしています）。

## 3. ふたの部品を付ける

| 部品 | 付け方 | 基板とのつなぎ |
|---|---|---|
| OLED（U3） | ふたの裏のくぼみに入れ、四隅をホットボンドで留める | ジャンパーワイヤーで J3（GND・VCC・SCL・SDA の印刷どおりに） |
| LED（LED1） | ふたの裏から穴に押し込み、ホットボンドで留める | 足にジャンパーワイヤーを挿して J4（R・G・B・いちばん長い足が K） |
| 押しボタン（SW1） | 前の壁の穴に通し、ナットで締める | J5（どちらの足でもよい） |

OLED は、ピンヘッダーを付けずに線をじかにはんだ付けすると、薄く収まります。

## 4. ファームウェアを書き込む

1. [Arduino IDE 2](https://www.arduino.cc/en/software) を入れます。
2. **ボードマネージャー**で「esp32 by Espressif Systems」（3.3 以降）を入れます。
3. **ライブラリマネージャー**で「Adafruit SSD1306」を入れます（Adafruit GFX と Adafruit BusIO も一緒に入ります）。
4. `firmware/QuakeScope/QuakeScope.ino` を開きます。
5. 「ツール」で次のように選びます。
   - ボード: **ESP32 Dev Module**
   - Partition Scheme: **Minimal SPIFFS (1.9MB APP with OTA/190KB SPIFFS)**（これを選ばないと、大きすぎて書き込めません）
   - ポート: ESP32 をつないだときに増えたもの
6. 「書き込み」を押します。

コマンドで書き込むときは:

```sh
arduino-cli compile --fqbn esp32:esp32:esp32:PartitionScheme=min_spiffs firmware/QuakeScope
arduino-cli upload  --fqbn esp32:esp32:esp32:PartitionScheme=min_spiffs -p <ポート> firmware/QuakeScope
```

2 回目からは、本体の設定画面の「本体」タブから、Wi-Fi 経由で書き込めます（[使い方](manual.md#ファームウェアの更新)）。

## 5. 動かしてみる

1. USB をつなぐと、画面に `QuakeScope v1.0.0 CALIBRATING` と出て、短い音が鳴ります。
2. 画面に `SETUP connect to:` と出たら成功です。[使い方](manual.md)の「はじめの設定」に進みます。

| 症状 | 確かめること |
|---|---|
| 画面が真っ暗 | OLED の VCC と GND が逆になっていないか。SDA と SCL が入れ替わっていないか |
| 画面に `NO SENSOR` | U2 の SDA・SCL・VCC・GND。AD0 が GND につながっているか |
| LED が紫に点滅 | センサーの値がおかしい（[使い方](manual.md#led-の色)） |
| 音が鳴らない | ブザーが「発振回路なし」か。Q1 の向き（E・C・B） |
| 書き込みで止まる | ESP32 の BOOT ボタンを押したまま、書き込みを始める |

## 6. 置く

- **建物の柱の近くの床**か、**壁に固定した、がたつかないたな**に、耳を木ねじで留めます。ねじが使えないときは、強力な両面テープで。
- 置いたら、本体が向きを測り直すまで（電源を入れてから約 15 秒）動かさないでください。
- 傾いていても、どの向きでも動きます（重力の向きを自分で測ります）。壁に縦に付けることもできます。
- 高い階や、たなの上では、建物やたなが揺れを大きくするため、気象庁の震度より大きく出ることがあります。

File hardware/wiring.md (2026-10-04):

<!-- tools/hw/layout.py が作ったファイルです。手で直さないでください -->
# 基板の配置と配線表

基板: 95×72 mm・2.54 mm ピッチ（例: サンハヤト ICB-293GV）。穴の番号は、部品面を上にして左上の穴が (1, 1)、右へ x、下へ y です。

基板の配置と配線

## 部品の位置

| 部品 | 品名 | 穴（ピン） | メモ |
|---|---|---|---|
| U1 | ESP32-DevKitC-32E | ソケット 2 本: (1〜19, 3) と (1〜19, 13)。(19, 3) が 3V3、(1, 3) が 5V | ピンソケットに挿す（高さ約 8.5 mm） |
| U2 | GY-521（MPU6050） | VCC (2, 17)、GND (3, 17)、SCL (4, 17)、SDA (5, 17)、XDA (6, 17)、XCL (7, 17)、AD0 (8, 17)、INT (9, 17) | ピンヘッダーの黒い台を抜いて低く付け、基板とのすき間に薄い両面テープ（クッションのないもの）を挟んで密着させる |
| BZ1 | 電磁ブザー 12 mm | + (28, 4)、- (31, 4) | 足の間隔 7.6 mm |
| D1 | 1N4148 | K (28, 7)、A (31, 7) | カソード（帯）を左（5V 側） |
| Q1 | 2SC1815 | E (28, 10)、C (29, 10)、B (30, 10) | 平らな面を手前（下）に、左から E C B |
| R1 | 1kΩ | a (30, 13)、b (33, 13) |  |
| R2 | 10kΩ | a (30, 16)、b (33, 16) |  |
| C1 | 100µF 16V | + (24, 4)、- (24, 5) | 足の長い方（+）を上 |
| R3 | 330Ω | a (13, 17)、b (16, 17) |  |
| R4 | 100Ω | a (13, 19)、b (16, 19) |  |
| R5 | 100Ω | a (13, 21)、b (16, 21) |  |
| J3 | OLED へ（L 型ピンヘッダー 1×4） | GND (22, 20)、VCC (23, 20)、SCL (24, 20)、SDA (25, 20) |  |
| J4 | LED へ（L 型ピンヘッダー 1×4） | R (22, 23)、G (23, 23)、B (24, 23)、K (25, 23) |  |
| J5 | ボタンへ（L 型ピンヘッダー 1×2） | BTN (27, 23)、GND (28, 23) |  |

## 配線表

上から順につなぐと、抜けがありません。1 本つないだら、テスターの導通チェックで確かめてください。

| # | ネット | から | へ | から（穴） | へ（穴） |
|---|---|---|---|---|---|
| 1 | +5V | U1 5V | U2 VCC | (1, 3) | (2, 17) |
| 2 | +5V | U2 VCC | C1 + | (2, 17) | (24, 4) |
| 3 | +5V | C1 + | BZ1 + | (24, 4) | (28, 4) |
| 4 | +5V | BZ1 + | D1 K | (28, 4) | (28, 7) |
| 5 | +3.3V | U1 3V3 | J3 VCC | (19, 3) | (23, 20) |
| 6 | GND | U1 GND | J3 GND | (19, 13) | (22, 20) |
| 7 | GND | J3 GND | J4 K | (22, 20) | (25, 23) |
| 8 | GND | J4 K | J5 GND | (25, 23) | (28, 23) |
| 9 | GND | U1 GND | U2 GND | (13, 13) | (3, 17) |
| 10 | GND | U2 GND | U2 AD0 | (3, 17) | (8, 17) |
| 11 | GND | U1 GND | Q1 E | (19, 13) | (28, 10) |
| 12 | GND | Q1 E | R2 | (28, 10) | (33, 16) |
| 13 | GND | Q1 E | C1 - | (28, 10) | (24, 5) |
| 14 | SDA | U1 IO21 | U2 SDA | (14, 13) | (5, 17) |
| 15 | SDA | U2 SDA | J3 SDA | (5, 17) | (25, 20) |
| 16 | SCL | U1 IO22 | U2 SCL | (17, 13) | (4, 17) |
| 17 | SCL | U2 SCL | J3 SCL | (4, 17) | (24, 20) |
| 18 | BUZ | U1 IO25 | R1 | (11, 3) | (33, 13) |
| 19 | Q1 ベース | R1 | Q1 B | (30, 13) | (30, 10) |
| 20 | Q1 ベース | Q1 B | R2 | (30, 10) | (30, 16) |
| 21 | ブザー − | BZ1 - | D1 A | (31, 4) | (31, 7) |
| 22 | ブザー − | D1 A | Q1 C | (31, 7) | (29, 10) |
| 23 | LED_R | U1 IO26 | R3 | (10, 3) | (13, 17) |
| 24 | LED_R | R3 | J4 R | (16, 17) | (22, 23) |
| 25 | LED_G | U1 IO27 | R4 | (9, 3) | (13, 19) |
| 26 | LED_G | R4 | J4 G | (16, 19) | (23, 23) |
| 27 | LED_B | U1 IO14 | R5 | (8, 3) | (13, 21) |
| 28 | LED_B | R5 | J4 B | (16, 21) | (24, 23) |
| 29 | BTN | U1 IO33 | J5 BTN | (12, 3) | (27, 23) |

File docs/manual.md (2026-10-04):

# 使い方

QuakeScope は、置いた場所の揺れを測り、気象庁の「計測震度」と同じ考え方で計算した**震度相当**を出す揺れ検知アラームです。強い揺れでは警報音を鳴らし、スマホに通知を送ります。

> 本機の値は、置いた場所で測った揺れからの**推定（参考値）**です。気象庁の発表する震度・緊急地震速報ではありません。揺れを感じたら、まず身の安全を確保してください。

## はじめの設定

初めて電源を入れると、本体が自分の Wi-Fi を出して「設定モード」になります（LED が青く点滅）。

1. 本体の画面に、次のように出ます。
   ```
   SETUP  connect to:
   QuakeScope-1A2B
   PASS 12345678
   then open
   http://192.168.4.1
   ```
2. スマホの Wi-Fi 設定で `QuakeScope-1A2B` を選び、`PASS` のあとの 8 けたを入れます（本体ごとに違います）。
3. 設定の画面が自動で開きます。開かないときは、ブラウザーで `http://192.168.4.1` を開きます。
4. 次の 4 つを入れて「保存して再起動」を押します。
   - **Wi-Fi のネットワーク**（2.4 GHz のもの。ESP32 は 5 GHz につなげません）と **パスワード**
   - **置く場所の名前**（通知の文に入ります。例: リビング）
   - **設定用のパスワード**（8 文字以上。あとで設定を変えるときに使います）
5. 本体が再起動して家の Wi-Fi につながると、LED がゆっくり緑に明滅します。

設定をやり直すときは、ボタンを押しながら電源を入れると、設定モードに入ります。

## 設定の画面を開く

スマホやパソコンを本体と同じ Wi-Fi につないで、ブラウザーで次のどちらかを開きます。

- `http://QuakeScope-1A2B.local/`（`1A2B` は本体ごとに違う。画面の 2 行目と同じ）
- 本体のボタンを短く押すと、画面に IP アドレスが出ます。`http://192.168.1.23/` のように開きます

| タブ | できること |
|---|---|
| いまの揺れ | いまの震度相当・この揺れの最大・最大加速度・直近の波形 |
| 記録 | これまでの揺れの一覧（最大 50 件）。行を押すと、その揺れの波形（新しい 8 件まで） |
| 通知の履歴 | 送った通知と、成功したか（最大 20 件） |
| 設定 | 警報の目安・音の大きさ・通知先（設定用のパスワードが要ります） |
| 本体 | Wi-Fi の強さ・空き容量・センサーの状態・警報音のテスト・向きを測り直す・記録を消す・初期状態に戻す |

## 本体の画面

```
12:34:56        W      ← 時刻、W = Wi-Fi につながっている（- = つながっていない）、M = 音を消している
SHINDO 4               ← 揺れているとき: 震度相当（5-=5弱、5+=5強）。いつもは NORMAL
NOW 2.6   MAX 3.9      ← いまの値と、この揺れの最大（計測震度相当）
▁▂▅▇▅▃▂▁               ← 直近 12.8 秒の揺れの大きさ
```

注意・警報のときは、2 行目が白黒反転します。

## LED の色

| 色 | 意味 |
|---|---|
| 緑（ゆっくり明るさが変わる） | 平常。見張っている |
| 水色 | 準備中（電源を入れてから約 15 秒、向きと雑音を測っている） |
| 黄 | 揺れを検知（震度 1 相当以上） |
| 橙の点滅 | 注意（初期設定では震度 3 相当以上） |
| 赤の速い点滅 | 警報（初期設定では震度 5 弱相当以上） |
| 紫の点滅 | センサーの異常（値が止まった・重力の大きさがおかしい・値が届かない） |
| 青の点滅 | 設定モード |

## 音

| 音 | いつ | 長さ |
|---|---|---|
| ピピッ | 揺れを検知 | 一瞬 |
| ピー・ピー（くり返し） | 注意 | 30 秒 |
| ピポピポ（高い音・くり返し） | 警報 | 60 秒 |

ボタンを短く押すと止まります。音の大きさは設定の画面で 0〜100 にできます（0 にすると鳴りません。画面に `M` が出ます）。

## ボタン

| 押し方 | すること |
|---|---|
| 短く押す | 鳴っている警報音を止める。鳴っていなければ、名前・IP アドレス・版を 5 秒表示 |
| 3 秒押して離す | 警報音のテスト |
| 10 秒押して離す | 初期状態に戻す（Wi-Fi・通知先・記録をすべて消す）。10 秒で画面に確認が出る |
| 押しながら電源を入れる | 設定モード |

## 警報の目安

設定の画面の「警報の目安」で変えられます。

| 項目 | 初期設定 | 選べる値 |
|---|---|---|
| 注意（警報音・通知） | 震度 3 相当（計測震度 2.5） | 震度 2〜4 相当 |
| 警報（強い警報音・通知） | 震度 5 弱相当（計測震度 4.5） | 震度 4〜5 強相当 |
| 通知する揺れ | 注意から | 注意から・警報だけ |

- 1 回の揺れで、同じレベルの通知は 1 度だけ送ります。揺れが収まると「おさまりました」のまとめを送ります（通知した揺れのときだけ）。
- 通知は 1 時間に 12 通までにしています（壊れたときに送り続けないように）。**警報は、この上限に関係なく送ります。**

## 通知

LINE・Telegram・Discord・メールに送れます。いくつでも同時に使えます。設定のしかたは[通知の設定](notifications.md)を見てください。設定の画面の「テスト通知を送る」で、届くか確かめられます。

## 揺れの記録

- 揺れるたびに、最大の震度相当・最大加速度・続いた時間・揺れ始めの時刻を残します（最大 50 件。古いものから消えます）。
- 揺れ始めの 5 秒前からの波形（3 方向、毎秒 50 回）を、新しい 8 件まで残します。
- 記録は本体の中だけにあり、外には送りません。

## ファームウェアの更新

設定の画面の「本体」タブの `/update` を開き、ユーザー名 `admin` と設定用のパスワードを入れて、新しいファームウェア（`.bin`）を選びます。Arduino IDE の「スケッチ」→「コンパイル済みバイナリをエクスポート」で作れます。

## 置き場所と精度

- **建物の柱の近くの床**や、**壁に固定したたな**に、耳をねじで留めるのがいちばん正確です。置いただけだと、強い揺れで本体がずれて、値が乱れます。
- 気象庁の震度計は地面や低い建物の 1 階に置かれています。**高い階や、たなの上では、気象庁の震度より大きく出る**ことがあります。
- 本体のセンサー（MPU6050）は雑音が大きく、置いておくだけで震度 1.5 相当ほどの値が出ます。本体はこの「平常時の値」を測り続け、それより十分大きい揺れだけを揺れとみなします。そのため、**震度 2 相当以下の小さな揺れは見逃すことがあります。** 震度 3 相当以上の揺れの判定には影響しません。
- 電源を入れてから約 15 秒は準備中で、揺れを判定しません。

## 停電と通信

- 停電すると、本体も Wi-Fi のルーターも止まります。給電しながら充電できるモバイルバッテリーをつなぐと、本体は動き続けて警報音を鳴らせます（ルーターが止まると通知は届きません）。
- インターネットが混み合うと、通知が遅れたり届かなかったりします。本体は 3 回まで送り直します。**通知だけに頼らないでください。**

## 困ったとき

| 症状 | すること |
|---|---|
| 家の Wi-Fi につながらない（画面に `-`） | 2.4 GHz のネットワークか。パスワードの大文字・小文字。ボタンを押しながら電源を入れて、設定し直す |
| 通知が届かない | 「通知の履歴」でエラーを見る。「テスト通知を送る」を押す。[通知の設定](notifications.md#うまくいかないとき) |
| 何もないのに検知する | 洗濯機・エアコンの室外機・道路の近くなど、いつも揺れている場所を避ける。たなに置いているなら床へ |
| 時刻が出ない | インターネットにつながると、自動で合います（NTP） |
| 設定用のパスワードを忘れた | ボタンを 10 秒押して初期状態に戻し、設定し直す |

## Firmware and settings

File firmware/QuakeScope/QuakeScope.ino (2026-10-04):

// QuakeScope — 揺れ検知アラーム（ESP32 + MPU6050）
//
// 置いた場所の揺れを 100 Hz で測り、気象庁の計測震度の方法に近い計算で「震度相当」を求める。
// 揺れ始め（P 波）で短い音、震度 3 相当で警報音とスマートフォンへの通知、震度 5 弱相当で強い警報音。
// 揺れは本体に記録し、家の Wi-Fi の中から Web 画面で見られる。
//
// ボード: ESP32 Dev Module（ESP32-DevKitC など）／ パーティション: 「Minimal SPIFFS (1.9MB APP with OTA/190KB SPIFFS)」
// ライブラリー: Adafruit SSD1306、Adafruit GFX Library（Arduino IDE のライブラリーマネージャーから）
// 配線と組み立て: docs/assembly.md
//
// ※ 本機の震度は推定値（参考値）です。気象庁の発表する震度ではありません。

#include <ESPmDNS.h>
#include <WiFi.h>
#include <Wire.h>
#include <time.h>

#include "src/app/context.h"
#include "src/app/display.h"
#include "src/app/sensor.h"
#include "src/app/web.h"
#include "src/qs/notify.h"
#include "src/qs/screen.h"

using namespace app;

namespace app {
Context ctx;

qs::WallTime wallFromEpoch(time_t t) {
    qs::WallTime w;
    if (t < 1700000000) return w;   // 時刻が合っていない
    struct tm tmv;
    localtime_r(&t, &tmv);
    w.year = tmv.tm_year + 1900; w.month = tmv.tm_mon + 1; w.day = tmv.tm_mday;
    w.hour = tmv.tm_hour; w.minute = tmv.tm_min; w.second = tmv.tm_sec;
    return w;
}
qs::WallTime wallNow() { return wallFromEpoch(time(nullptr)); }
}  // namespace app

namespace {

Mpu6050 mpu;
Display display;
Recorder recorder;
QueueHandle_t eventQueue;
volatile bool recHold = false;     // 記録を保存している間は、記録に書き込まない
volatile int recLength = 0;
volatile uint32_t lastSampleMs = 0;
qs::NotifyPolicy policy;
uint32_t infoUntil = 0;
bool faultNotified = false;

// ------------------------------------------------------------ 計測（専用のタスク、20 ms ごと）

void sensorTask(void *) {
    TickType_t last = xTaskGetTickCount();
    uint32_t retryAt = 0;
    for (;;) {
        vTaskDelayUntil(&last, pdMS_TO_TICKS(20));
        if (!mpu.ok()) {
            if (millis() > retryAt) { retryAt = millis() + 3000; mpu.begin(Wire); }
            continue;
        }
        xSemaphoreTake(ctx.engineLock, portMAX_DELAY);
        if (ctx.requestCalibrate) { ctx.engine.reset(); ctx.requestCalibrate = false; }
        const int n = mpu.read([](double x, double y, double z) {
            ctx.engine.push(x, y, z);
            double d[3];
            ctx.engine.lastDynamic(d);
            if (!recHold) recorder.push(d[0], d[1], d[2]);
            qs::EngineEvent ev;
            while (ctx.engine.poll(ev)) {
                if (ev.type == qs::EventType::ShakeStart && !recHold) recorder.begin(500);   // 5 秒前から
                if (ev.type == qs::EventType::ShakeEnd && recorder.recording()) {
                    recLength = recorder.end();
                    recHold = true;
                }
                xQueueSend(eventQueue, &ev, 0);
            }
        });
        xSemaphoreGive(ctx.engineLock);
        if (n > 0) lastSampleMs = millis();
    }
}

// ------------------------------------------------------------ 出来事への対応（音・通知・記録）

void notify(const qs::EngineEvent &ev) {
    if (!policy.shouldSend(ev, millis() / 1000.0)) return;
    qs::MessageContext mc;
    mc.place = ctx.settings.place.c_str();
    mc.when = wallNow();
    const time_t now = time(nullptr);
    mc.start = wallFromEpoch(now - static_cast<time_t>(ev.time - ev.startTime + 0.5));
    qs::NotifyMessage m;
    if (qs::makeMessage(ev, mc, m)) ctx.notifier.enqueue(m, ctx.settings);
}

void handleEvent(const qs::EngineEvent &ev) {
    using qs::EventType;
    switch (ev.type) {
        case EventType::ShakeStart:
            if (ctx.settings.beepOnDetect) ctx.alarm.play(Sound::Detect);
            break;
        case EventType::LevelUp:
            if (ev.level == qs::Level::Warning) ctx.alarm.play(Sound::Warning);
            else if (ev.level == qs::Level::Caution) ctx.alarm.play(Sound::Caution);
            break;
        case EventType::ShakeEnd:
            if (recHold) {
                EventSummary s;
                const time_t now = time(nullptr);
                s.epochStart = now > 1700000000 ? static_cast<uint32_t>(now - (ev.time - ev.startTime)) : 0;
                s.duration = ev.duration;
                s.intensity = ev.intensity;
                s.shindo = qs::shindoLabel(ev.shindo);
                s.pga = ev.pga;
                s.level = static_cast<uint8_t>(ev.level);
                s.notified = static_cast<int>(ev.level) >= ctx.settings.notifyMinLevel;
                ctx.storage.save(s, recorder, recLength);
                recHold = false;
            }
            break;
        default:
            break;
    }
    notify(ev);
}

// ------------------------------------------------------------ ボタン

void handleButton() {
    static bool down = false;
    static uint32_t since = 0;
    static bool clicked3 = false, clicked10 = false;
    const bool pressed = digitalRead(pins::kButton) == LOW;
    const uint32_t now = millis();
    if (pressed && !down) { down = true; since = now; clicked3 = clicked10 = false; }
    if (pressed && down) {
        const uint32_t held = now - since;
        if (held > 3000 && !clicked3) { clicked3 = true; ctx.alarm.play(Sound::Click); }
        if (held > 10000 && !clicked10) {
            clicked10 = true;
            ctx.alarm.play(Sound::Click);
            display.showInfo("RESET ALL SETTINGS?", "release button now", "to reset");
            infoUntil = now + 4000;
        }
    }
    if (!pressed && down) {
        down = false;
        const uint32_t held = now - since;
        if (held < 50) return;   // チャタリング
        if (held >= 10000) {
            factoryReset();
            ESP.restart();
        } else if (held >= 3000) {
            ctx.requestTestAlarm = true;
        } else if (ctx.alarm.playing()) {
            ctx.alarm.stop();     // 警報音を止める
        } else {
            display.showInfo(deviceName(), WiFi.isConnected() ? WiFi.localIP().toString() : String("WiFi: not connected"),
                             "v" + String(kVersion));
            infoUntil = now + 5000;
        }
    }
}

// ------------------------------------------------------------ 画面と LED（0.1 秒ごと）

void updateUi() {
    static uint32_t last = 0;
    const uint32_t now = millis();
    if (now - last < 100) return;
    last = now;
    qs::EngineStatus st;
    qs::ScreenModel m;
    const qs::WallTime w = wallNow();
    qs::ScreenInput in;
    in.engine = &ctx.engine;
    if (w.valid()) { in.hour = w.hour; in.minute = w.minute; in.second = w.second; }
    in.wifi = WiFi.isConnected();
    in.setupMode = ctx.setupMode;
    in.muted = ctx.settings.volume == 0;
    xSemaphoreTake(ctx.engineLock, portMAX_DELAY);
    st = ctx.engine.status();
    qs::buildScreen(in, m);
    xSemaphoreGive(ctx.engineLock);

    LedMode led = LedMode::Normal;
    if (ctx.setupMode) led = LedMode::Setup;
    else if (!ctx.sensorAlive || !st.sensorOk) led = LedMode::Fault;
    else if (!st.calibrated) led = LedMode::Busy;
    else if (st.level == qs::Level::Warning) led = LedMode::Warning;
    else if (st.level == qs::Level::Caution) led = LedMode::Caution;
    else if (st.level == qs::Level::Detect) led = LedMode::Detect;
    ctx.alarm.setLed(led);

    if (static_cast<int32_t>(now - infoUntil) < 0) return;   // 情報の表示中
    if (ctx.setupMode) {
        static uint32_t lastSetup = 0;
        if (now - lastSetup > 2000) { lastSetup = now; display.showSetup(deviceName(), ctx.settings.apPass); }
        return;
    }
    if (!ctx.sensorAlive) std::snprintf(m.status, sizeof m.status, "NO SENSOR");
    display.show(m);
}

void startWifi() {
    WiFi.persistent(false);
    WiFi.setHostname(deviceName().c_str());
    if (ctx.setupMode) {
        WiFi.mode(WIFI_AP_STA);   // 近くの Wi-Fi を探せるように
        WiFi.softAP(deviceName().c_str(), ctx.settings.apPass.c_str());
    } else {
        WiFi.mode(WIFI_STA);
        WiFi.setAutoReconnect(true);
        WiFi.begin(ctx.settings.wifiSsid.c_str(), ctx.settings.wifiPass.c_str());
        configTzTime("JST-9", "ntp.nict.jp", "time.google.com", "pool.ntp.org");
    }
}

}  // namespace

void setup() {
    Serial.begin(115200);
    pinMode(pins::kButton, INPUT_PULLUP);
    loadSettings(ctx.settings);
    ctx.setupMode = !ctx.settings.configured() || digitalRead(pins::kButton) == LOW;  // ボタンを押しながら起動しても設定に入る

    ctx.alarm.begin(pins::kBuzzer, pins::kLedR, pins::kLedG, pins::kLedB);
    ctx.alarm.setVolume(ctx.settings.volume);
    ctx.alarm.setLed(LedMode::Busy);

    Wire.begin(pins::kSda, pins::kScl, 400000);
    display.begin(Wire, ctx.settings.oledHeight);
    display.showBoot(kVersion);
    ctx.alarm.play(Sound::Boot);
    if (!mpu.begin(Wire)) Serial.println("MPU6050 が見つかりません（配線を確かめてください）");

    ctx.storage.begin();
    ctx.engineLock = xSemaphoreCreateMutex();
    qs::EngineConfig cfg;
    cfg.cautionIntensity = ctx.settings.cautionIntensity;
    cfg.warningIntensity = ctx.settings.warningIntensity;
    ctx.engine.setConfig(cfg);
    ctx.recorder = &recorder;

    qs::NotifyPolicyConfig pc;
    pc.minLevel = static_cast<qs::Level>(ctx.settings.notifyMinLevel);
    pc.sendEnd = ctx.settings.sendEnd;
    policy.setConfig(pc);

    eventQueue = xQueueCreate(32, sizeof(qs::EngineEvent));
    ctx.notifier.begin();
    startWifi();
    webBegin();
    // 計測は CPU の 1 番で、高い優先度で動かす（Wi-Fi は 0 番）
    xTaskCreatePinnedToCore(sensorTask, "sensor", 8192, nullptr, 10, nullptr, 1);
    lastSampleMs = millis();
}

void loop() {
    webLoop();

    qs::EngineEvent ev;
    while (xQueueReceive(eventQueue, &ev, 0) == pdTRUE) handleEvent(ev);

    // 設定の変更（通知の条件）を反映
    qs::NotifyPolicyConfig pc = policy.config();
    pc.minLevel = static_cast<qs::Level>(ctx.settings.notifyMinLevel);
    pc.sendEnd = ctx.settings.sendEnd;
    policy.setConfig(pc);

    // センサーから値が届いているか
    const bool alive = millis() - lastSampleMs < 3000;
    if (!alive && ctx.sensorAlive && millis() > 10000) {
        ctx.sensorAlive = false;
        if (!faultNotified) {
            faultNotified = true;
            qs::EngineEvent f;
            f.type = qs::EventType::SensorFault;
            f.value = 3;
            notify(f);
        }
    } else if (alive) {
        ctx.sensorAlive = true;
    }

    if (ctx.requestTestAlarm) { ctx.requestTestAlarm = false; ctx.alarm.play(Sound::Test); }
    if (ctx.requestTestNotify) {
        ctx.requestTestNotify = false;
        qs::MessageContext mc;
        mc.place = ctx.settings.place.c_str();
        mc.when = wallNow();
        ctx.notifier.enqueue(qs::makeTestMessage(mc), ctx.settings);
    }
    if (ctx.requestReboot) { delay(500); ESP.restart(); }

    handleButton();
    ctx.alarm.update();
    updateUi();
    delay(5);
}

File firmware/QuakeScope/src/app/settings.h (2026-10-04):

// 設定（本体の中の不揮発メモリー「NVS」に保存する）と、ピンの割り当て。
#pragma once

#include <Arduino.h>

namespace app {

// ESP32-DevKitC（ESP32-WROOM-32E）のピン。起動時に使われるピン（0, 2, 5, 12, 15）は避けている
namespace pins {
constexpr int kSda = 21;      // I²C（加速度センサーと OLED で共有）
constexpr int kScl = 22;
constexpr int kBuzzer = 25;   // NPN トランジスター経由でブザーを鳴らす
constexpr int kLedR = 26;     // RGB LED（カソードコモン）
constexpr int kLedG = 27;
constexpr int kLedB = 14;
constexpr int kButton = 33;   // 押すと GND（内部プルアップ）
}  // namespace pins

struct Settings {
    // Wi-Fi
    String wifiSsid, wifiPass;
    // 本体
    String place = "自宅";          // 通知に入れる場所の名前
    String adminPass;              // 設定を変えるときのパスワード（8 文字以上）
    String apPass;                 // 初期設定のときの Wi-Fi のパスワード（最初の起動で作る）
    uint8_t oledHeight = 64;       // 64 または 32
    bool beepOnDetect = true;      // 揺れ始め（震度 1 相当〜）で短く鳴らす
    uint8_t volume = 100;          // 0〜100
    float cautionIntensity = 2.5;  // 注意（震度 3 相当）
    float warningIntensity = 4.5;  // 警報（震度 5 弱相当）
    // 通知
    uint8_t notifyMinLevel = 2;    // 2: 注意から、3: 警報だけ
    bool sendEnd = true;           // 収まったときにまとめを送る
    bool lineOn = false;   String lineToken, lineUser;
    bool tgOn = false;     String tgToken, tgChat;
    bool dcOn = false;     String dcWebhook;
    bool mailOn = false;   String smtpHost, smtpUser, smtpPass, mailTo; uint16_t smtpPort = 465;

    bool configured() const { return wifiSsid.length() > 0 && adminPass.length() >= 8; }
};

void loadSettings(Settings &s);
void saveSettings(const Settings &s);
void factoryReset();
// 機器ごとの名前（"QuakeScope-1A2B"）
String deviceName();

}  // namespace app

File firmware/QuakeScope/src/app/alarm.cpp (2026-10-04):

#include "alarm.h"

namespace app {

namespace {

struct Step { uint16_t hz; uint16_t ms; };

// 音のパターン（周波数 0 は無音）。最後まで行ったら、鳴らす時間が残っていればくり返す
const Step kBoot[] = {{1500, 60}, {0, 40}, {2000, 80}};
const Step kClick[] = {{2500, 25}};
const Step kDetect[] = {{1200, 80}, {0, 80}, {1200, 80}};
const Step kCaution[] = {{2000, 200}, {0, 300}};
const Step kWarning[] = {{2400, 120}, {1800, 120}};

struct Pattern { const Step *steps; int n; uint32_t totalMs; int rank; };

Pattern pattern(Sound s) {
    switch (s) {
        case Sound::Boot: return {kBoot, 3, 180, 1};
        case Sound::Click: return {kClick, 1, 25, 1};
        case Sound::Detect: return {kDetect, 3, 240, 2};
        case Sound::Caution: return {kCaution, 2, 30000, 3};
        case Sound::Test: return {kCaution, 2, 3000, 3};
        case Sound::Warning: return {kWarning, 2, 60000, 4};
        default: return {nullptr, 0, 0, 0};
    }
}

}  // namespace

void Alarm::begin(int buzzerPin, int r, int g, int b) {
    buz_ = buzzerPin; r_ = r; g_ = g; b_ = b;
    ledcAttach(buz_, 2000, 10);
    ledcWrite(buz_, 0);
    ledcAttach(r_, 5000, 8);
    ledcAttach(g_, 5000, 8);
    ledcAttach(b_, 5000, 8);
    rgb(0, 0, 0);
}

void Alarm::tone(uint16_t hz) {
    if (hz == lastHz_) return;
    lastHz_ = hz;
    if (hz == 0 || volume_ == 0) { ledcWrite(buz_, 0); return; }
    ledcChangeFrequency(buz_, hz, 10);
    ledcWrite(buz_, 512u * volume_ / 100u);   // 50% が最大の音量
}

void Alarm::rgb(uint8_t r, uint8_t g, uint8_t b) {
    ledcWrite(r_, r);
    ledcWrite(g_, g);
    ledcWrite(b_, b);
}

void Alarm::play(Sound s) {
    if (pattern(s).rank < pattern(sound_).rank && playing()) return;  // 強い音を優先
    sound_ = s;
    started_ = stepAt_ = millis();
    until_ = started_ + pattern(s).totalMs;
    step_ = 0;
    lastHz_ = 0xFFFF;
    tone(pattern(s).steps ? pattern(s).steps[0].hz : 0);
}

void Alarm::stop() {
    sound_ = Sound::None;
    tone(0);
}

void Alarm::update() {
    const uint32_t now = millis();
    if (sound_ != Sound::None) {
        const Pattern p = pattern(sound_);
        if (static_cast<int32_t>(now - until_) >= 0) {
            stop();
        } else if (now - stepAt_ >= p.steps[step_].ms) {
            stepAt_ = now;
            step_ = (step_ + 1) % p.n;
            tone(p.steps[step_].hz);
        }
    }
    // LED
    const bool blinkSlow = (now / 500) % 2 == 0, blinkFast = (now / 150) % 2 == 0;
    switch (led_) {
        case LedMode::Off: rgb(0, 0, 0); break;
        case LedMode::Normal: {
            // ゆっくり明るさを変える（動いていることが分かるように）
            const int ph = (now / 8) % 512;
            const uint8_t v = 4 + (ph < 256 ? ph : 511 - ph) / 16;
            rgb(0, v, 0);
            break;
        }
        case LedMode::Setup: rgb(0, 0, blinkSlow ? 60 : 0); break;
        case LedMode::Busy: rgb(0, 30, 60); break;
        case LedMode::Detect: rgb(120, 90, 0); break;
        case LedMode::Caution: rgb(blinkSlow ? 200 : 40, blinkSlow ? 70 : 10, 0); break;
        case LedMode::Warning: rgb(blinkFast ? 255 : 0, 0, 0); break;
        case LedMode::Fault: rgb(blinkSlow ? 120 : 0, 0, blinkSlow ? 120 : 0); break;
    }
}

}  // namespace app

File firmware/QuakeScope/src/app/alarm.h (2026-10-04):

// ブザーの音のパターンと、RGB LED の色。止めずに（ブロックせずに）動かす。
#pragma once

#include <Arduino.h>

namespace app {

enum class Sound : uint8_t { None, Boot, Click, Detect, Caution, Warning, Test };
enum class LedMode : uint8_t { Off, Normal, Setup, Detect, Caution, Warning, Fault, Busy };

class Alarm {
public:
    void begin(int buzzerPin, int r, int g, int b);
    void play(Sound s);          // 鳴らす（今より弱い音では上書きしない）
    void stop();                 // 止める（ボタン）
    bool playing() const { return sound_ != Sound::None; }
    Sound sound() const { return sound_; }
    void setVolume(uint8_t v) { volume_ = v > 100 ? 100 : v; }
    void setLed(LedMode m) { led_ = m; }
    void update();               // 10 ms ごとに呼ぶ

private:
    void tone(uint16_t hz);
    void rgb(uint8_t r, uint8_t g, uint8_t b);
    int buz_ = -1, r_ = -1, g_ = -1, b_ = -1;
    Sound sound_ = Sound::None;
    uint32_t started_ = 0, stepAt_ = 0, until_ = 0;
    int step_ = 0;
    uint8_t volume_ = 100;
    uint16_t lastHz_ = 0;
    LedMode led_ = LedMode::Off;
};

}  // namespace app

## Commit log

2026-10-04 QuakeScope: ESP32 の揺れ検知アラーム（震度相当・通知・ブラウザー版・ケースと基板）
    [case_base.stl, case_lid.stl]
2026-10-04 README に CI のバッジを追加
